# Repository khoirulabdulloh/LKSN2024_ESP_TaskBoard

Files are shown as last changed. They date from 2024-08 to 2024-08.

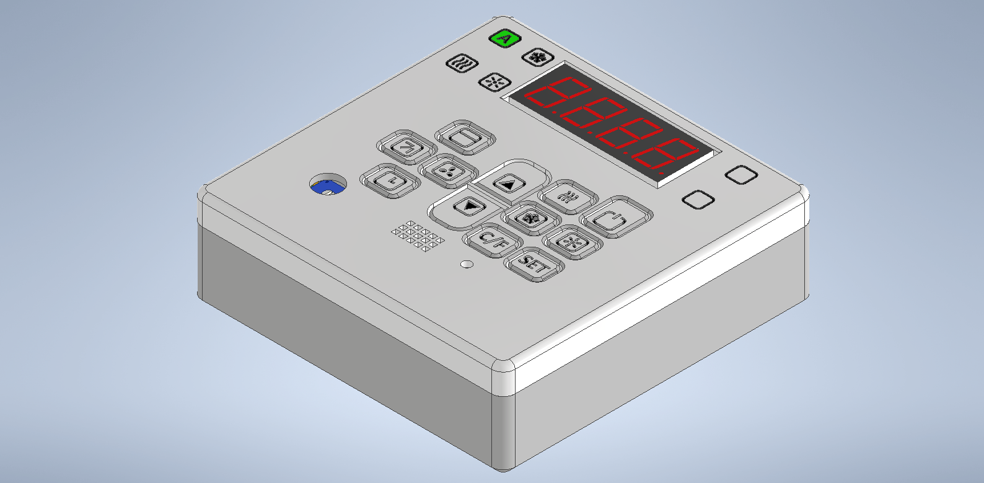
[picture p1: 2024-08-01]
Assembly_LKS2024_ESP_ACController_2.png

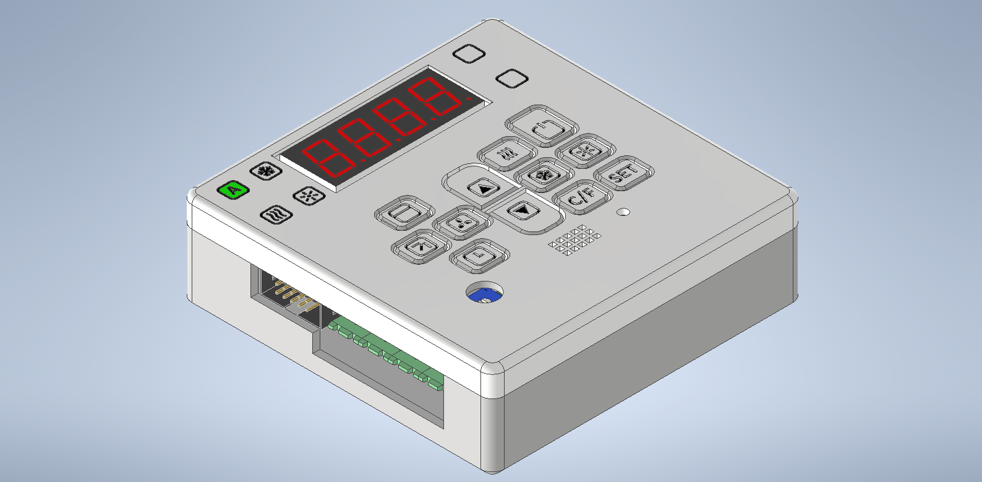
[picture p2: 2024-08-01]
Assembly_LKS2024_ESP_ACController_3.png

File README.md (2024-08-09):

# LKSN2024_ESP_TaskBoard
Embedded System Programming Task Board for Lomba Kompetensi Siswa Nasional Tahun 2024

 -Template_Program berisi template untuk pemrogramaan saat lomba, template akan terus update hingga H-3 perlombaan
 
 -file *.sch* merupakan schematic file EAGLE atau Fusion360

 -file *.brd* merupakan layout file EAGLE atau Fusion360

 -Schematic .pdf merupakan schematic file yang sudah di export dalam PDF

 -file .png merupakan foto dari TaskProject

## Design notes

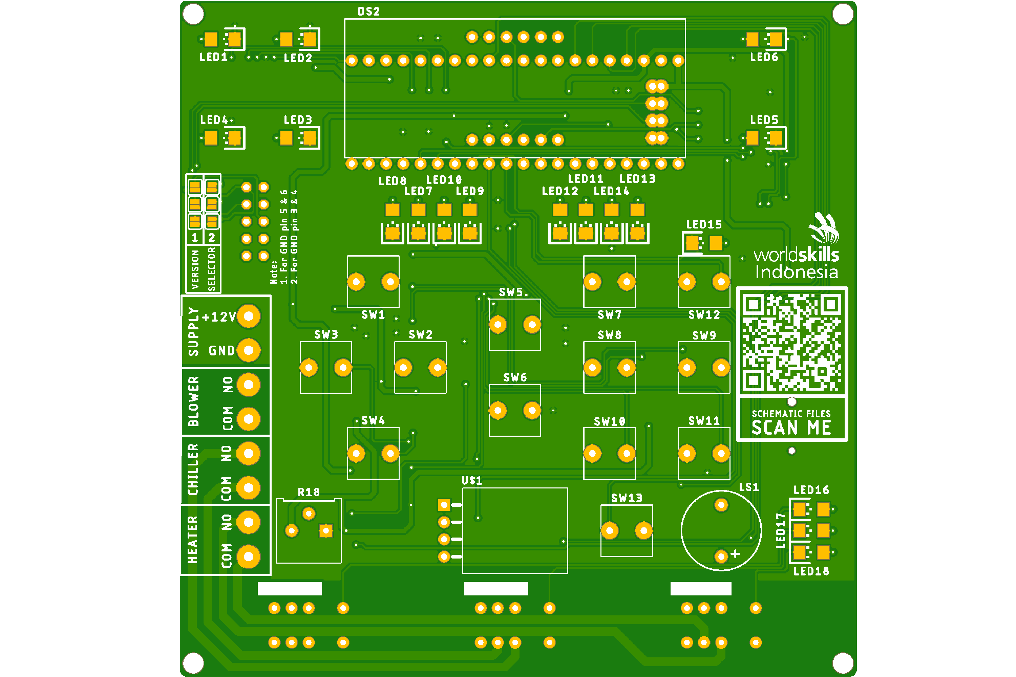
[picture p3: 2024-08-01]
TopSide_LKS2024_ESP_ACController.png

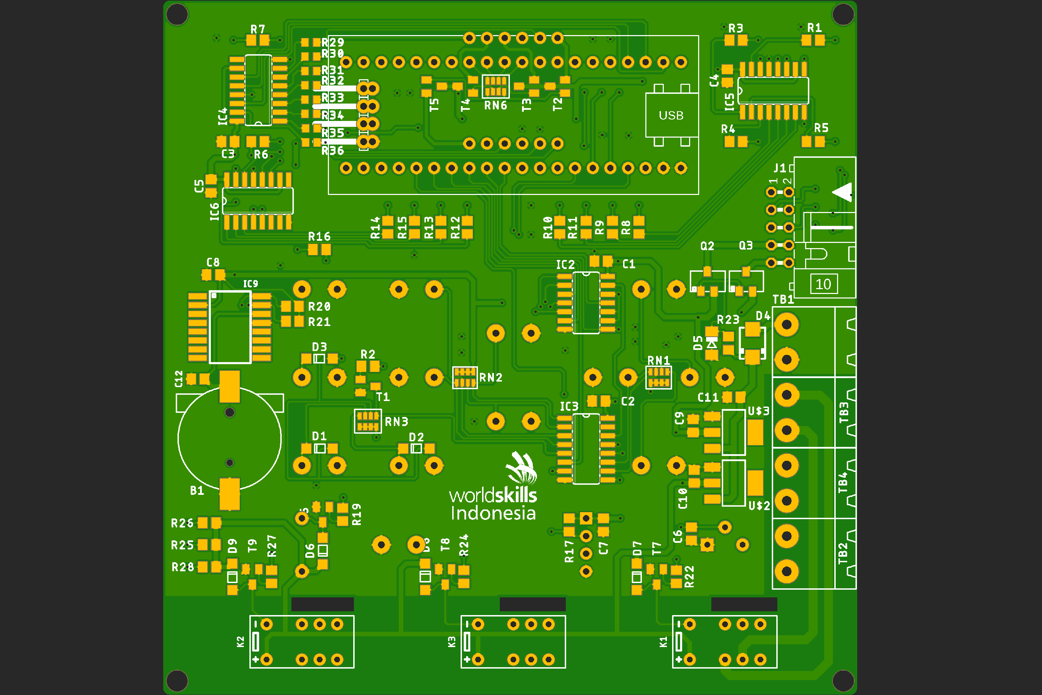
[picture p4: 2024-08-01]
BottomSide_LKS2024_ESP_ACController.png

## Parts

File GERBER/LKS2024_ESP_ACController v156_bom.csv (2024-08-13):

Comment | Designator | Footprint | LCSC Part #
 | J1 | ML10L
1N4148T4 | D1 D2 D3 D6 D7 D8 D9 | SOD123
1k | RN6 | 0603-ARC
1k | R2 R16 R19 R22 R24 R27 | R0805
1k5 | R1 R3 R4 R5 R6 R7 R8 R9 R10 R11 R12 R13 R14 R15 | R0805
3V3 | U$3 | SOT223
4k7 | R20 R21 | R0805
5V | U$2 | SOT223
5V1 | D5 | SOD80C
5k | R17 | R0805
7SEG-5463 | DS2 | 5643
10k | RN1 RN2 RN3 | 0603-ARC
10k | R18 | TRIM_3386P-1-101T
74HCT595D | IC4 IC5 IC6 | SO16
74LS08D | IC2 | SO14
74LS148D | IC3 | SO16
75 | R29 R30 R31 R32 R33 R34 R35 R36 | R0603
100k | R23 | R0805
100n | C1 C2 C3 C4 C5 C6 C7 C8 C9 C10 C11 C12 | C0805
330 | R25 R26 R28 | R0805
AO3404 | Q2 Q3 | SOT23
BLOWER | TB3 | MSTBA2
BLUE | LED2 LED8 LED12 | CHIPLED_1206
BUZZER-PTH_KIT | LS1 | BUZZER-12MM-KIT
C/F | SW10 | PUSH_BUTTON_2P
CHILLER | TB4 | MSTBA2
CR1220 | B1 | CR1220
DHT11 | U$1 | DHT11
DS3231" | IC9 | SO16W
EC2 | K1 K2 K3 | EC2
F_COOL | SW8 | PUSH_BUTTON_2P
F_HEAT | SW9 | PUSH_BUTTON_2P
GREEN | LED1 LED7 LED9 LED10 LED11 LED13 LED14 LED15 LED16 LED17 LED18 | CHIPLED_1206
HEATER | TB2 | MSTBA2
HEATING | SW7 | PUSH_BUTTON_2P
JUMPER-SMT_2_NC_PASTE_SILK | JP3 JP4 JP5 JP8 JP9 JP10 | SMT-JUMPER_2_NC_PASTE_SILK
MMBT3904 | T1 T2 T3 T4 T5 T6 T7 T8 T9 | SOT23-BEC
MODE | SW1 | PUSH_BUTTON_2P
ON/OFF | SW12 | PUSH_BUTTON_2P
RED | LED3 | CHIPLED_1206
RST | SW13 | PUSH_BUTTON_2P
SET | SW11 | PUSH_BUTTON_2P
SPEED | SW2 | PUSH_BUTTON_2P
SS34 | D4 | SMA
STM32F103C8T6-MODULE-SYS | IC1 | STM32F103C8T6-MODULE-SYS
SUPPLY | TB1 | MSTBA2
SWEEP | SW3 | PUSH_BUTTON_2P
TEMP_DOWN | SW6 | PUSH_BUTTON_2P
TEMP_UP | SW5 | PUSH_BUTTON_2P
TIMER | SW4 | PUSH_BUTTON_2P
WHITE | LED4 LED5 LED6 | CHIPLED_1206

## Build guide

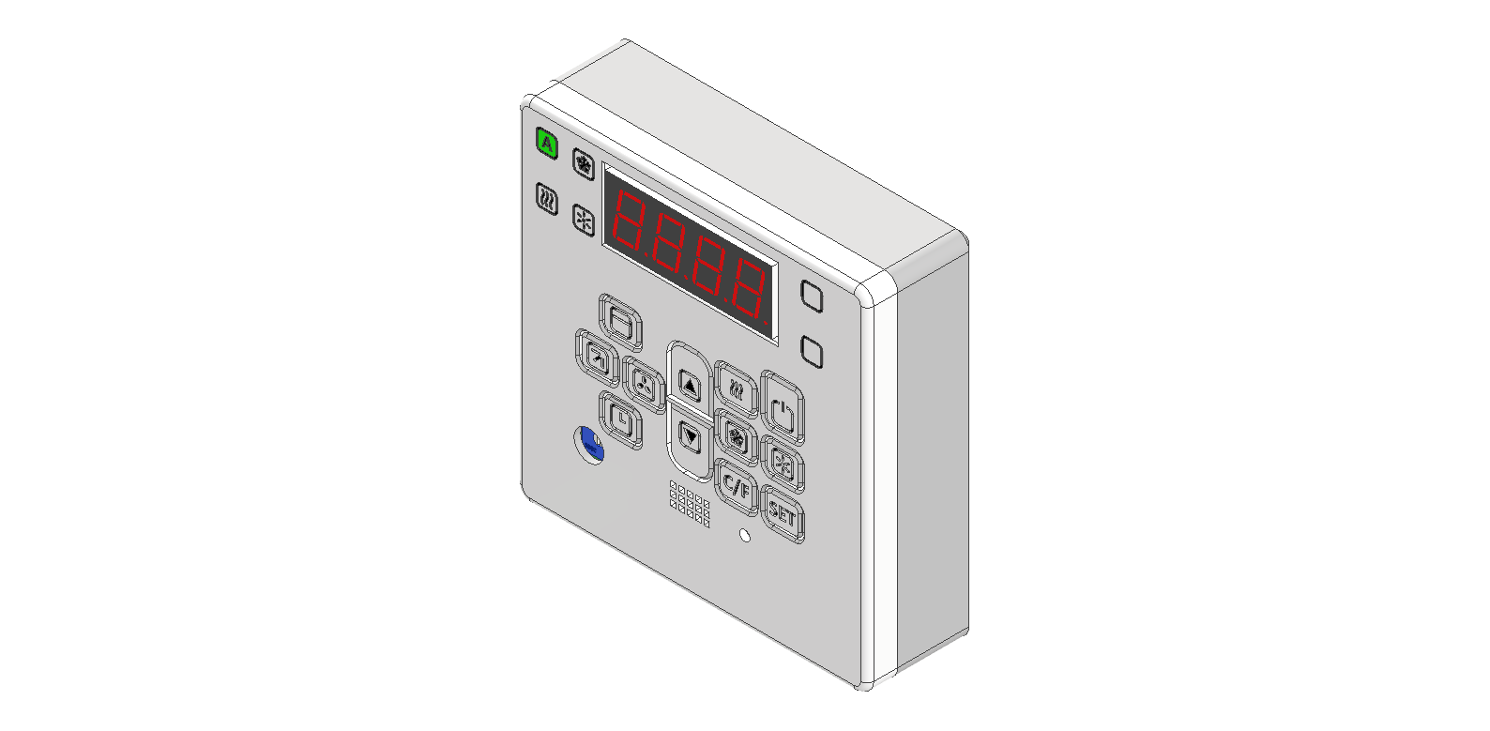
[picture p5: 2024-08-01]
Assembly_LKS2024_ESP_ACController_1.png

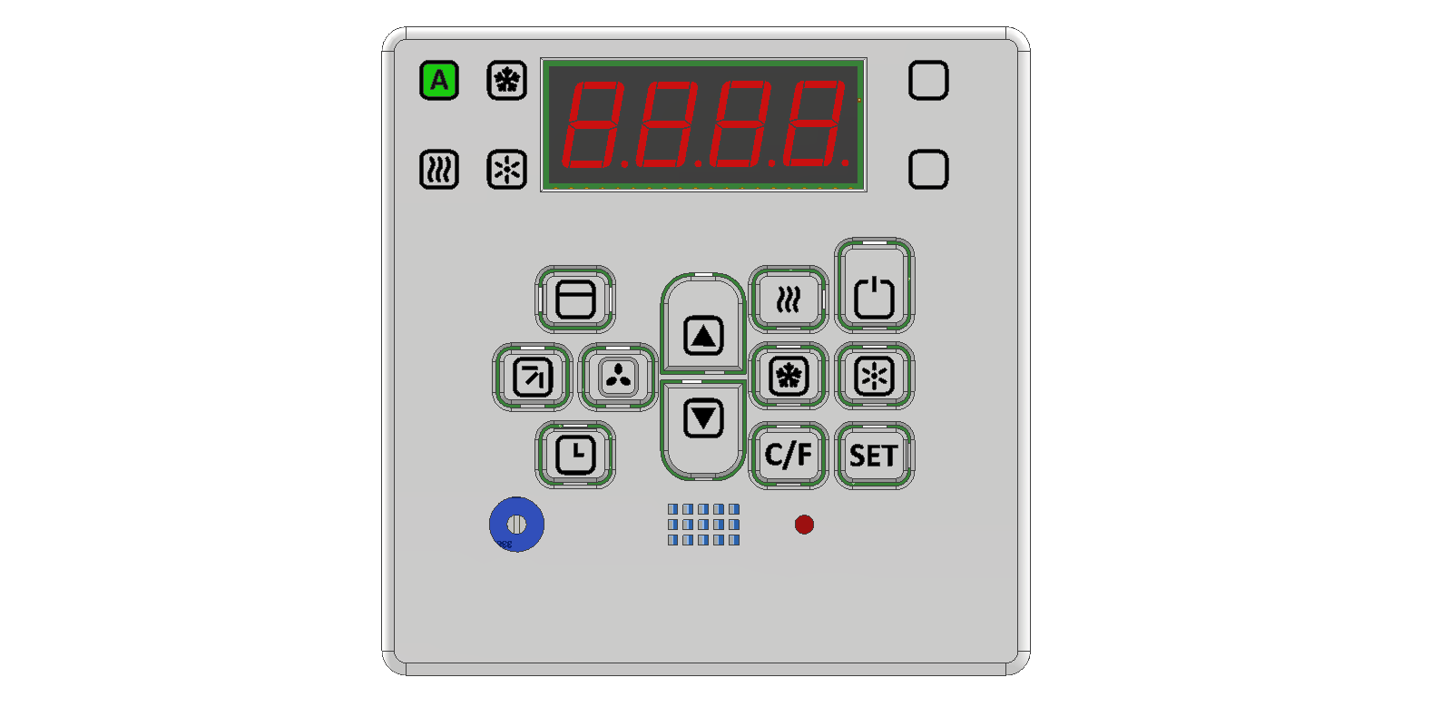
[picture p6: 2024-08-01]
Assembly_LKS2024_ESP_ACController v13.png

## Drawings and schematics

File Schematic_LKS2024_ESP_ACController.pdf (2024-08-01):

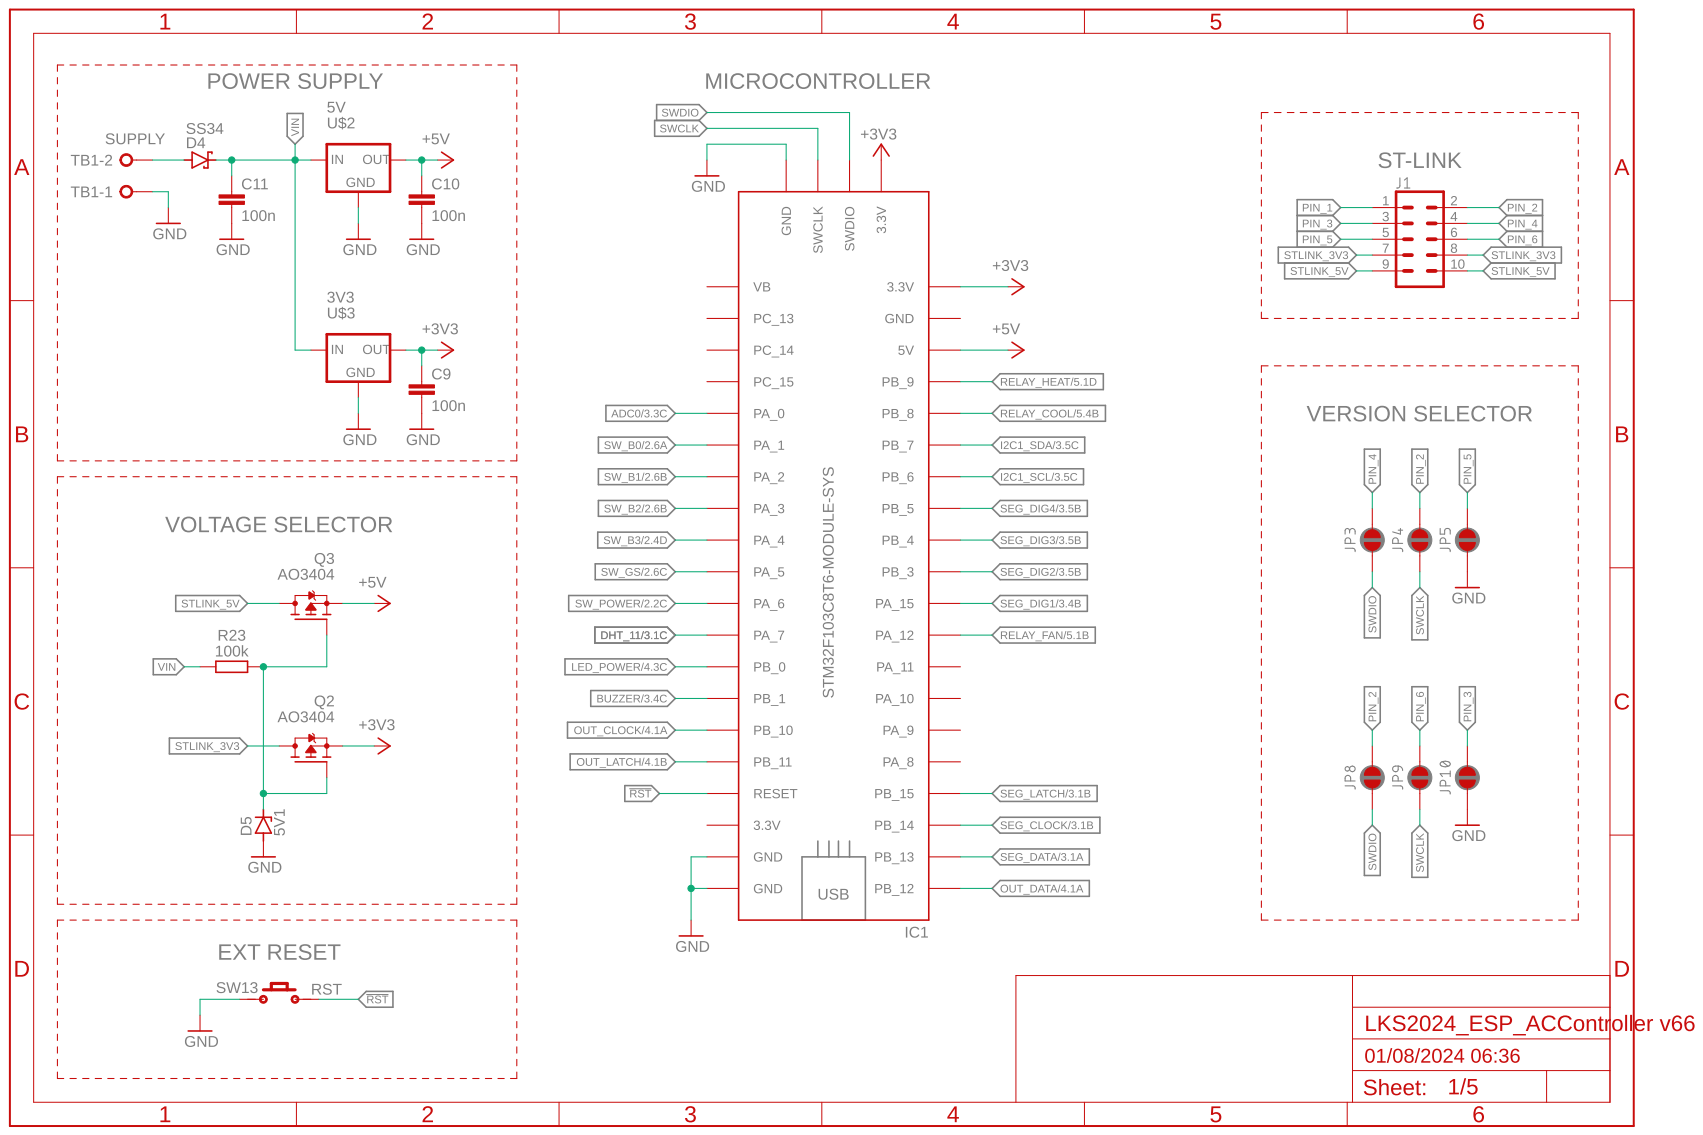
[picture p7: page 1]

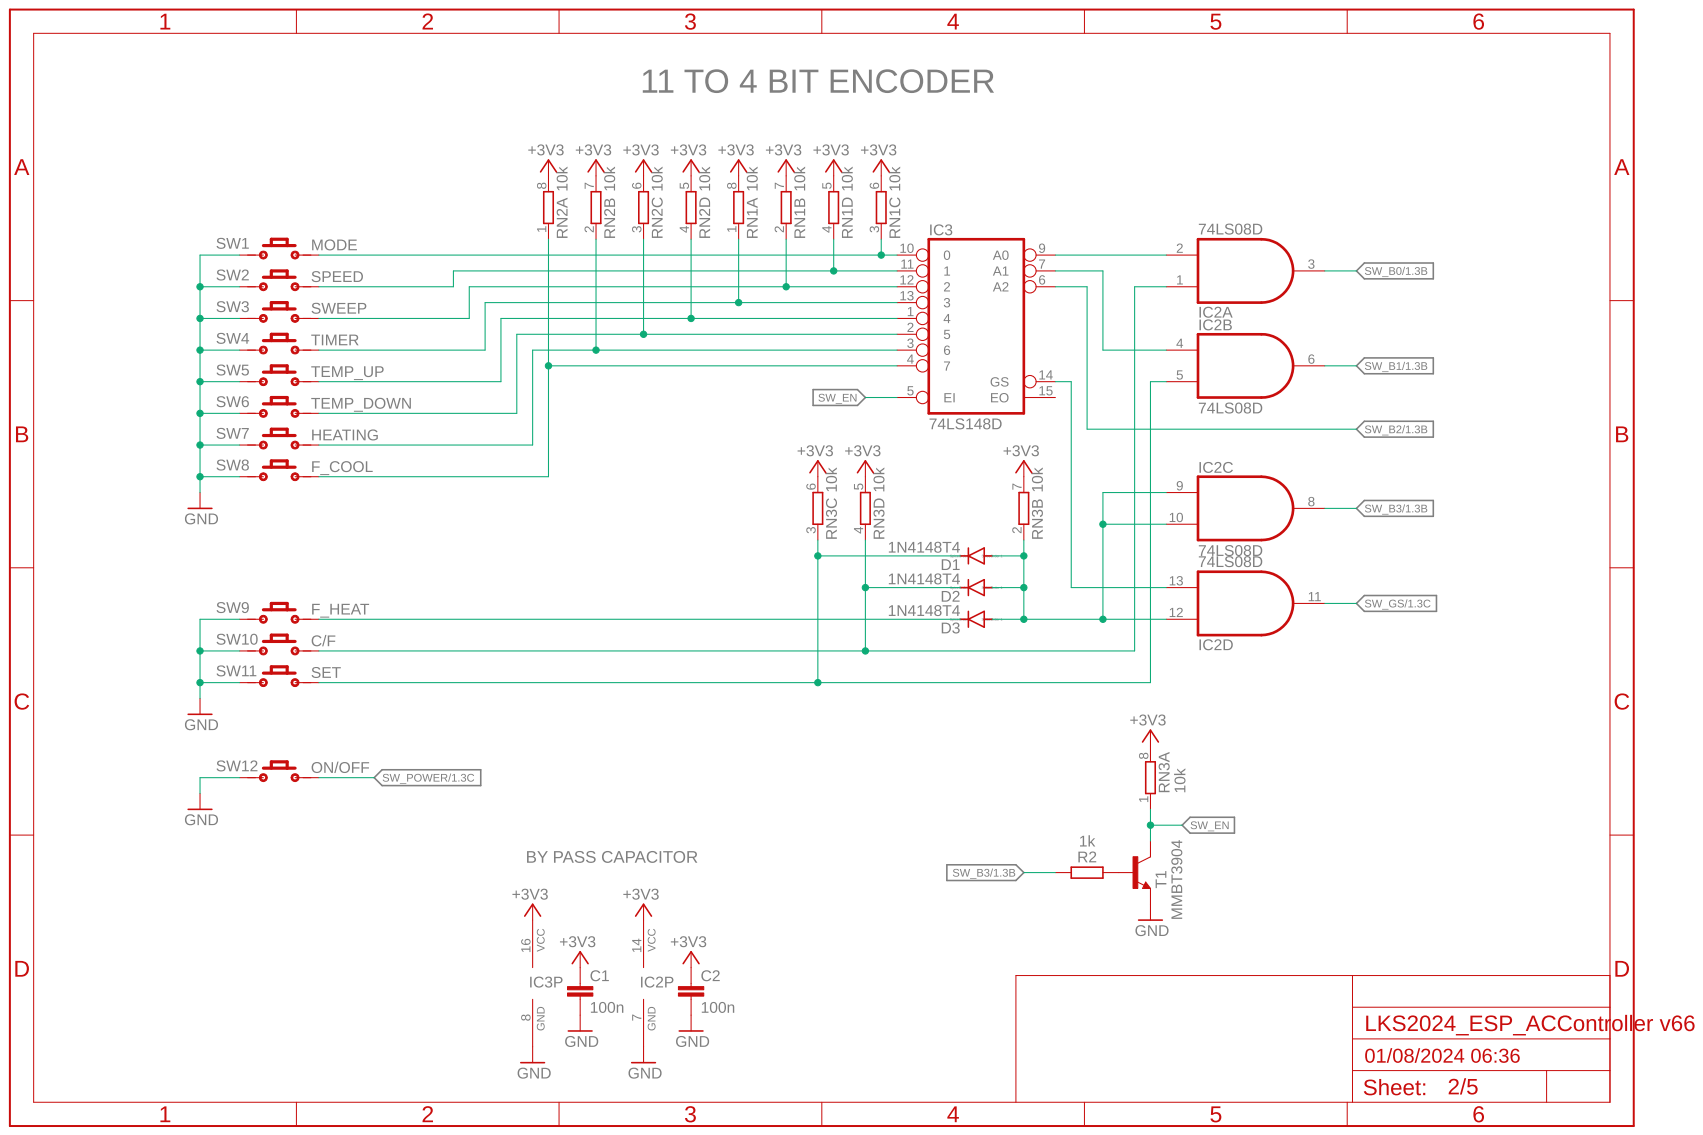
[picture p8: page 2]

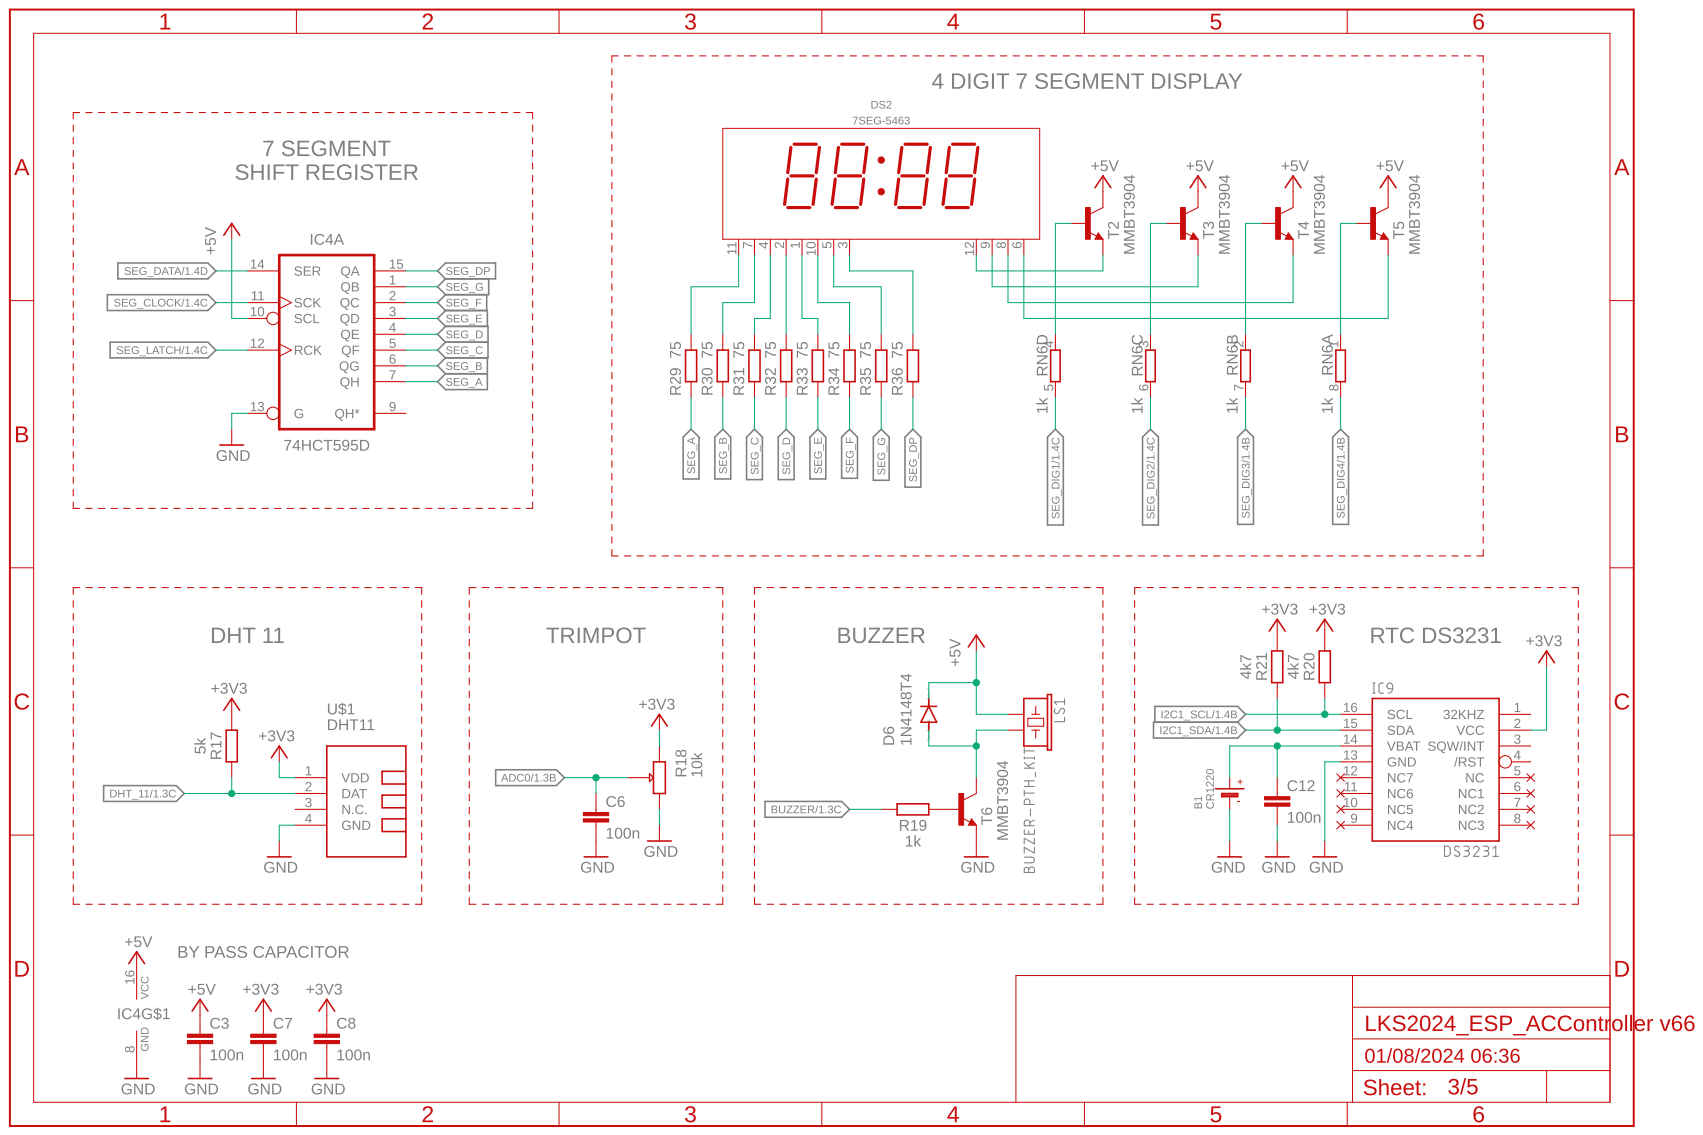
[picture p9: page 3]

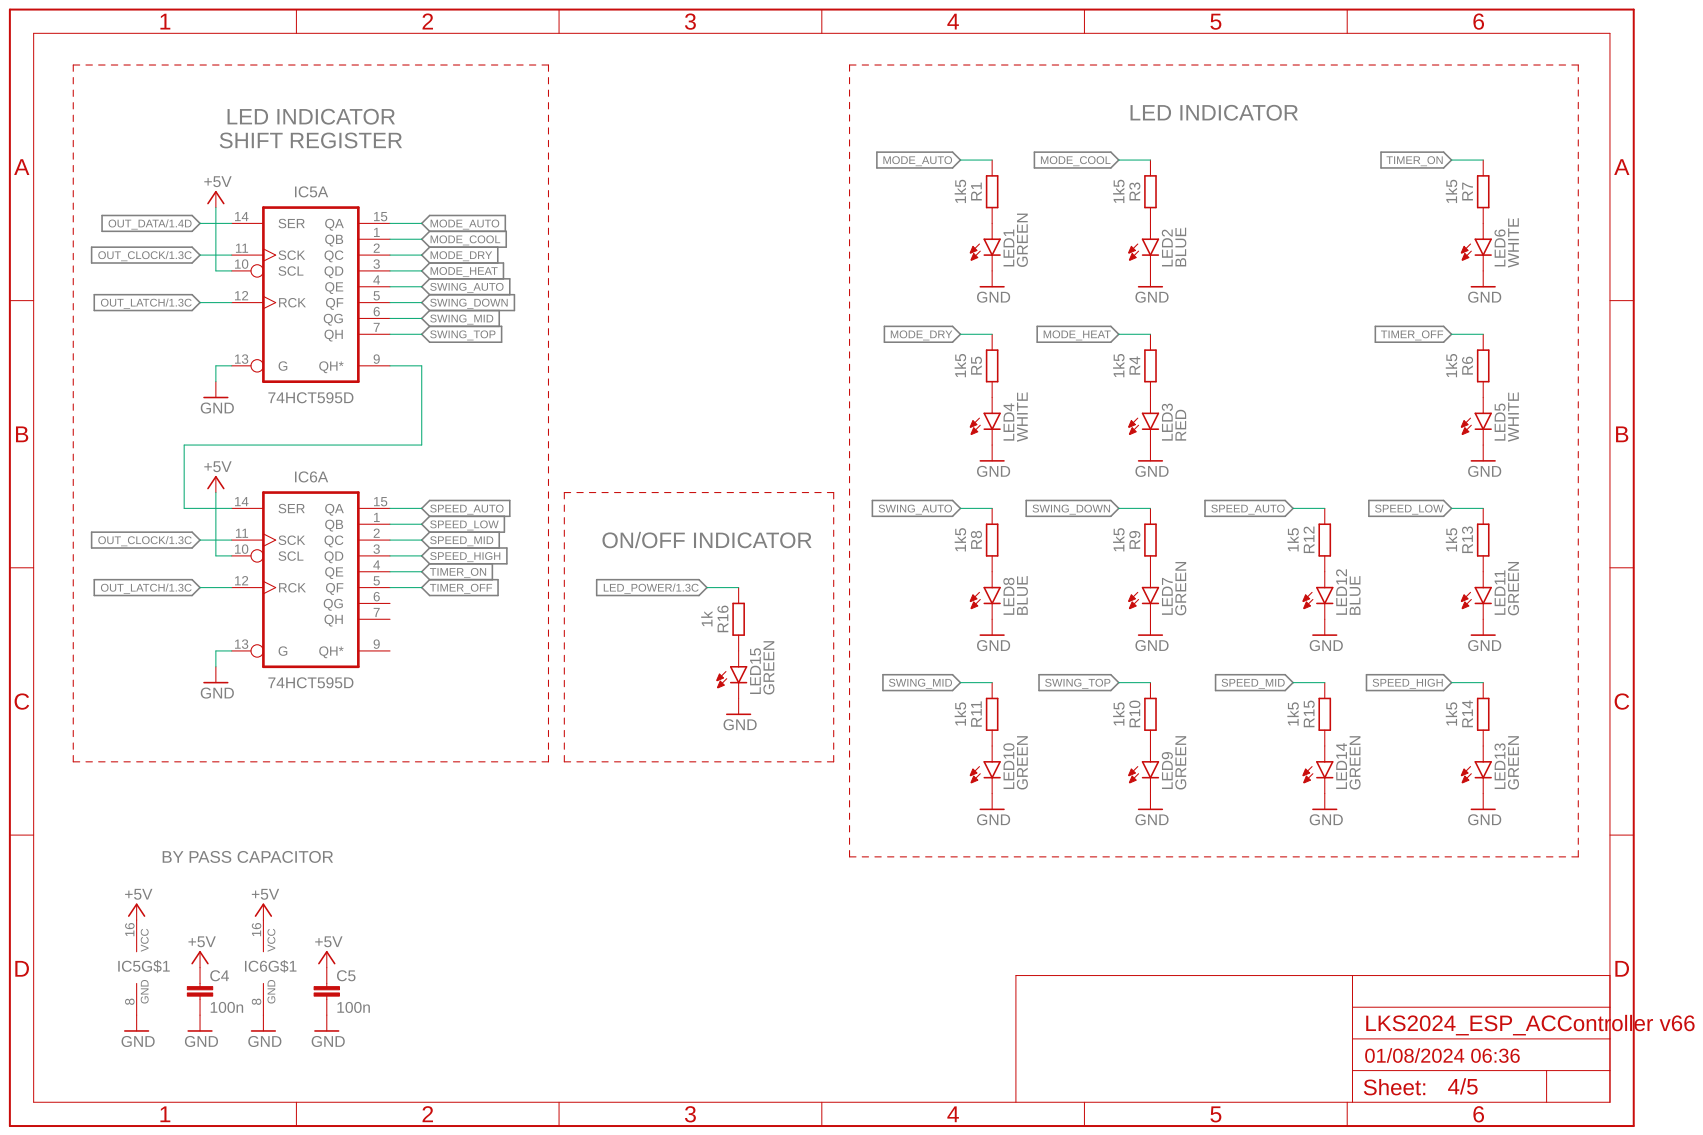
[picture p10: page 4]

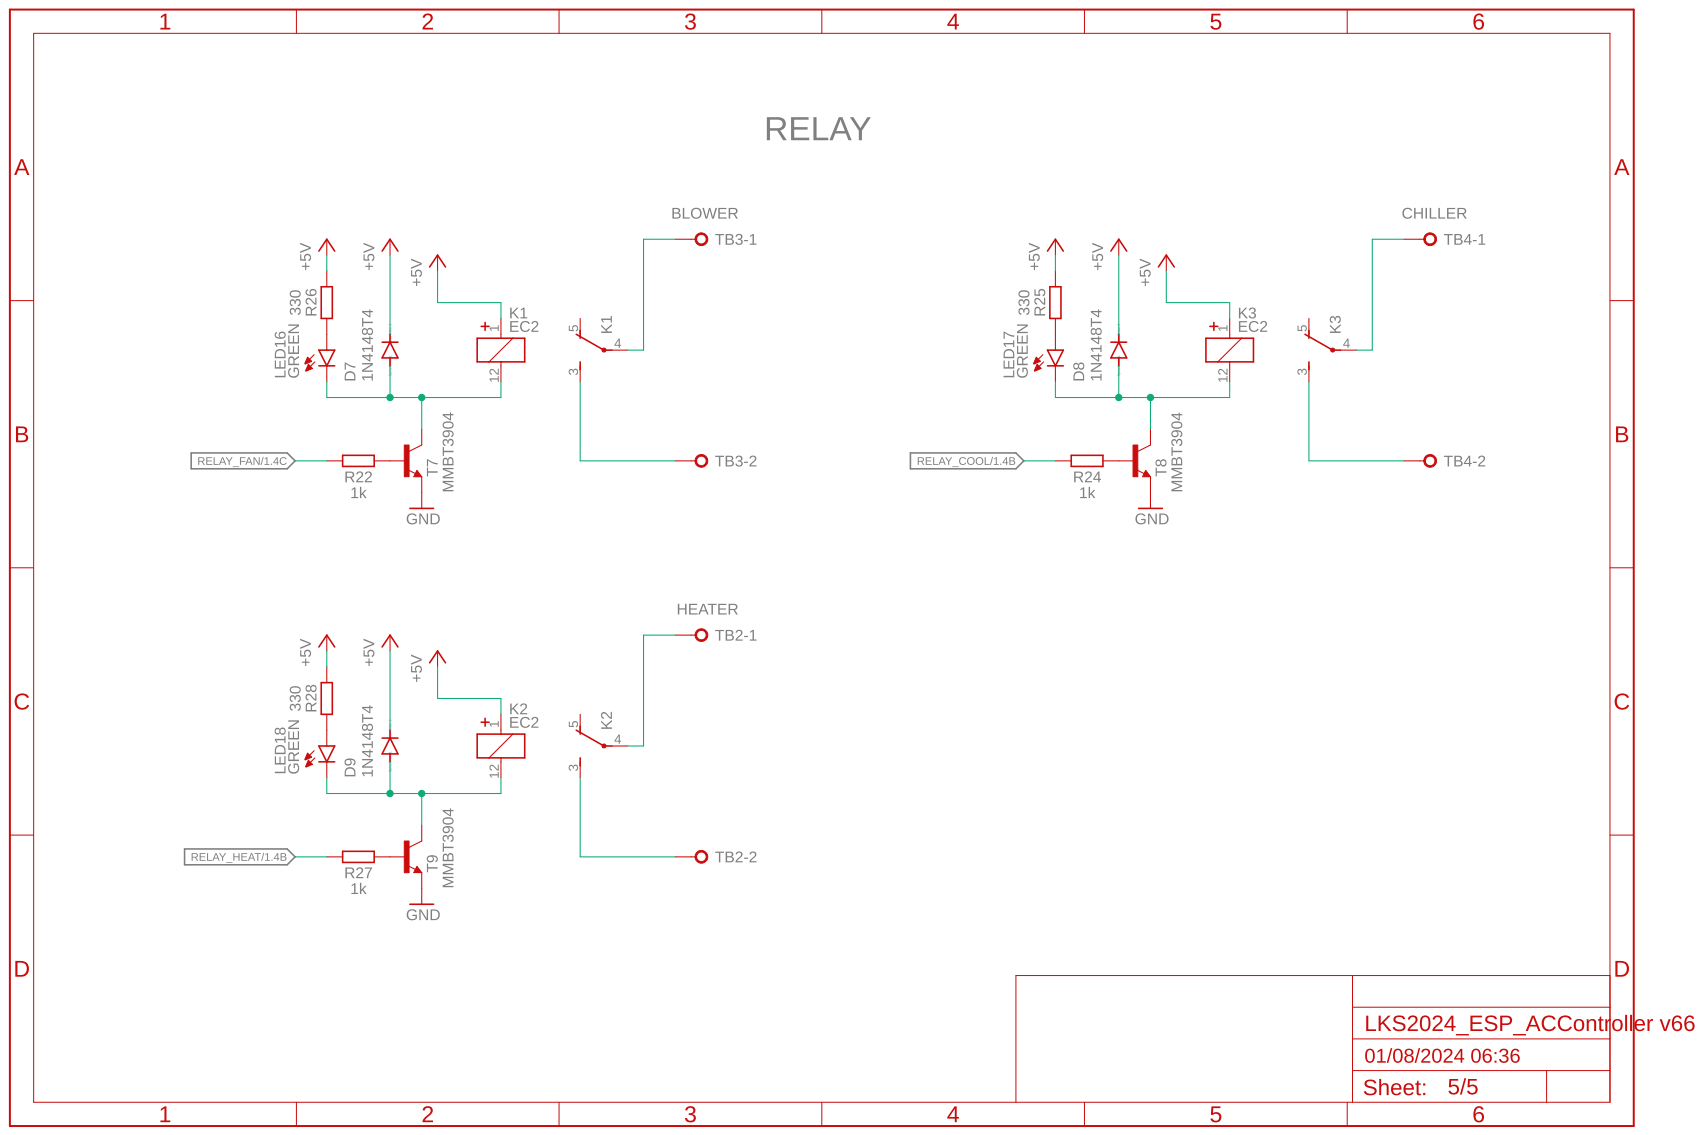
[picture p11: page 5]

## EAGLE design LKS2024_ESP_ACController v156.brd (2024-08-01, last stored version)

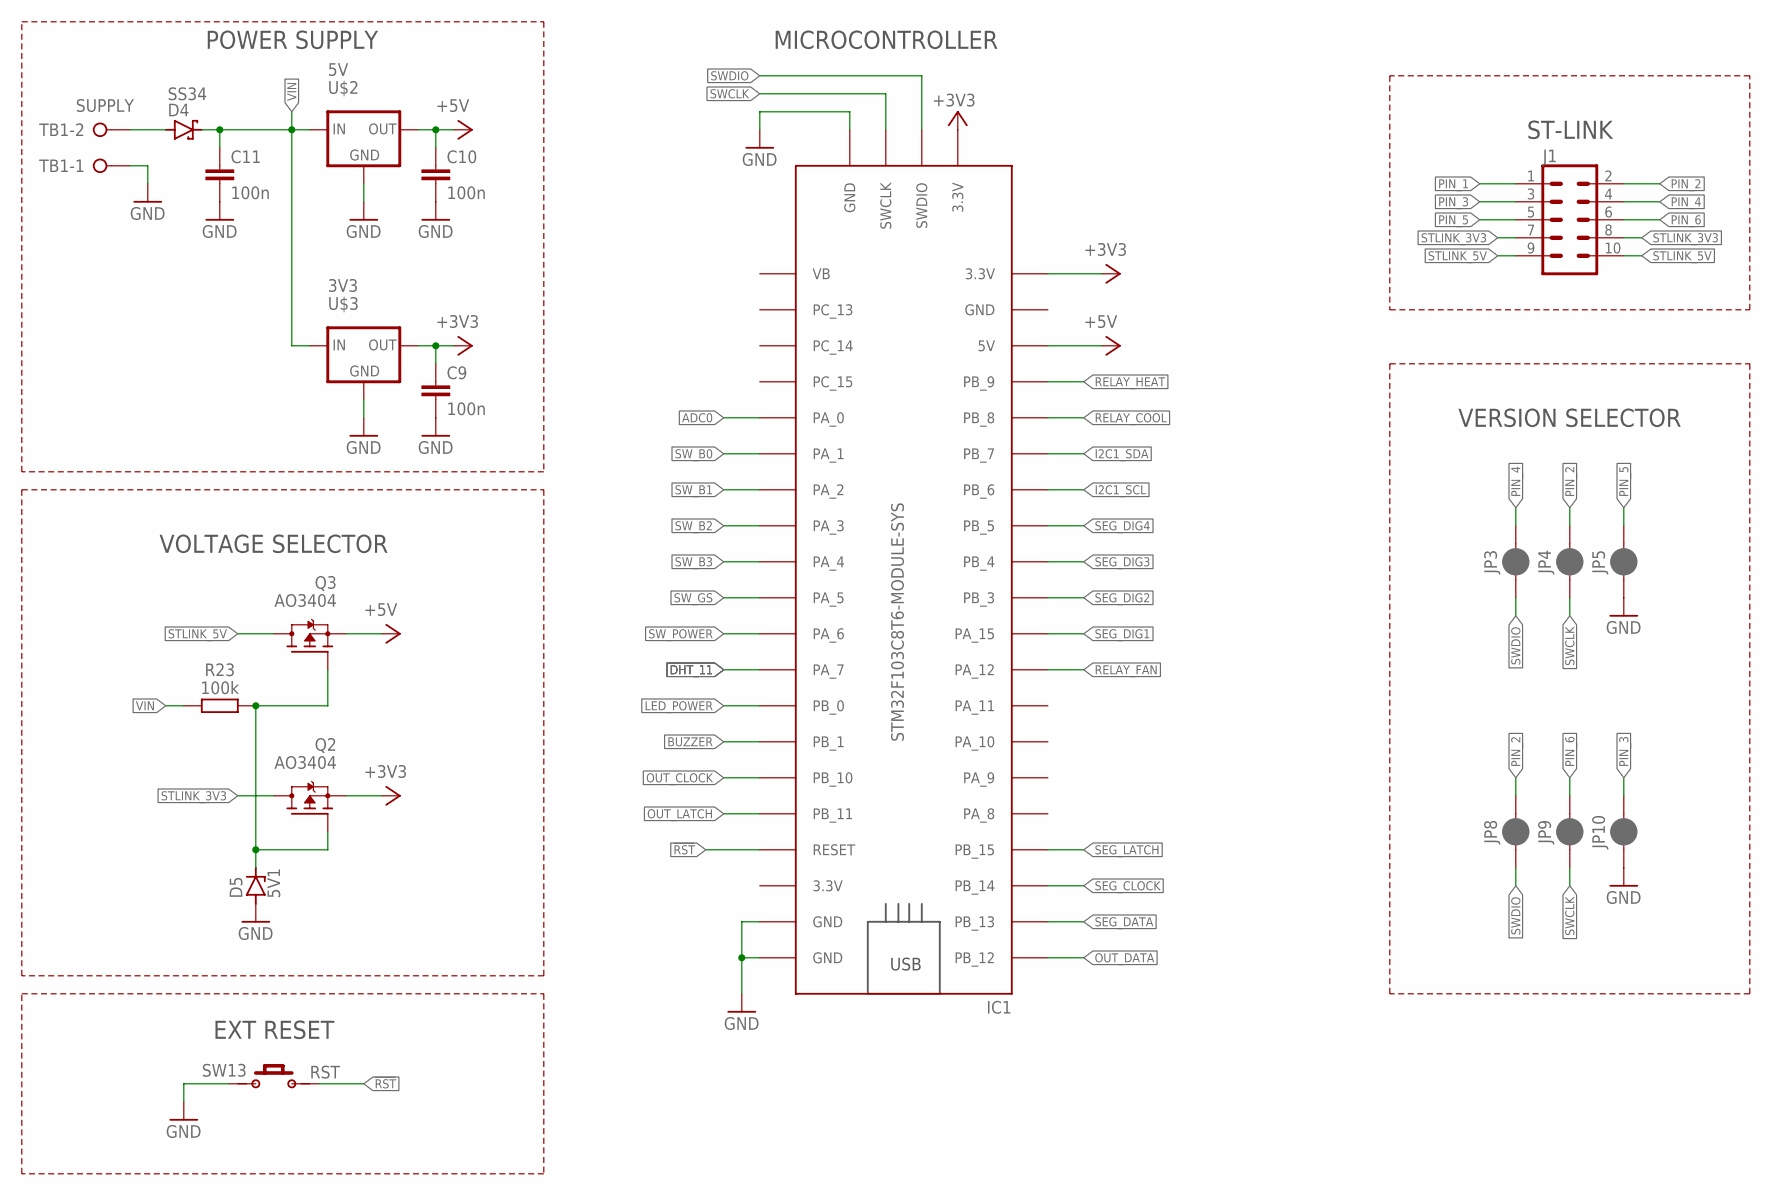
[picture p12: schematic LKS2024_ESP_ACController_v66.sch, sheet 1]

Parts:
C9, C10, C11: 100n; C0805
D4: SS34; SMA
D5: 5V1; SOD80C
IC1: STM32F103C8T6-MODULE-SYS
J1: CONN_05X2ML10L; ML10L
JP3, JP4, JP5, JP8, JP9, JP10: JUMPER-SMT_2_NC_PASTE_SILK; SMT-JUMPER_2_NC_PASTE_SILK
Q2, Q3: AO3404; SOT23
R23: 100k; R0805
SW13: RST; PUSH_BUTTON_2P
TB1: SUPPLY; MSTBA2
U$2: 5V; SOT223
U$3: 3V3; SOT223

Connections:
!RST: IC1.RESET, SW13.2
+3V3: C9.1, IC1.3.3V_1 (3.3V), IC1.3V3_1 (3.3V), IC1.3V3_3 (3.3V), Q2.2 (S), U$3.2 (OUT); also elsewhere on the board
+5V: C10.1, IC1.5V, Q3.2 (S), U$2.2 (OUT); also elsewhere on the board
ADC0: IC1.PA_0; also elsewhere on the board
BUZZER: IC1.PB_1; also elsewhere on the board
DHT_11: IC1.PA_7; also elsewhere on the board
GND: C9.2, C10.2, C11.2, D5.A, IC1.GND_2 (GND), IC1.GND_3 (GND), IC1.GND_4 (GND), IC1.GND_5 (GND), JP5.1, JP10.1, SW13.1, TB1.1, U$2.1 (GND), U$3.1 (GND); also elsewhere on the board
I2C1_SCL: IC1.PB_6; also elsewhere on the board
I2C1_SDA: IC1.PB_7; also elsewhere on the board
LED_POWER: IC1.PB_0; also elsewhere on the board
unnamed: D4.A, TB1.2
unnamed: D5.C, Q2.1 (G), Q3.1 (G), R23.2
OUT_CLOCK: IC1.PB_10; also elsewhere on the board
OUT_DATA: IC1.PB_12; also elsewhere on the board
OUT_LATCH: IC1.PB_11; also elsewhere on the board
PIN_1: J1.1
PIN_2: J1.2, JP4.2, JP8.2
PIN_3: J1.3, JP10.2
PIN_4: J1.4, JP3.2
PIN_5: J1.5, JP5.2
PIN_6: J1.6, JP9.2
RELAY_COOL: IC1.PB_8; also elsewhere on the board
RELAY_FAN: IC1.PA_12; also elsewhere on the board
RELAY_HEAT: IC1.PB_9; also elsewhere on the board
SEG_CLOCK: IC1.PB_14; also elsewhere on the board
SEG_DATA: IC1.PB_13; also elsewhere on the board
SEG_DIG1: IC1.PA_15; also elsewhere on the board
SEG_DIG2: IC1.PB_3; also elsewhere on the board
SEG_DIG3: IC1.PB_4; also elsewhere on the board
SEG_DIG4: IC1.PB_5; also elsewhere on the board
SEG_LATCH: IC1.PB_15; also elsewhere on the board
STLINK_3V3: J1.7, J1.8, Q2.3 (D)
STLINK_5V: J1.9, J1.10, Q3.3 (D)
SWCLK: IC1.SWCLK, IC1.SWCLK1 (SWCLK), JP4.1, JP9.1
SWDIO: IC1.SWDIO, IC1.SWDIO1 (SWDIO), JP3.1, JP8.1
SW_B0: IC1.PA_1; also elsewhere on the board
SW_B1: IC1.PA_2; also elsewhere on the board
SW_B2: IC1.PA_3; also elsewhere on the board
SW_B3: IC1.PA_4; also elsewhere on the board
SW_GS: IC1.PA_5; also elsewhere on the board
SW_POWER: IC1.PA_6; also elsewhere on the board
VIN: C11.1, D4.C, R23.1, U$2.3 (IN), U$3.3 (IN)

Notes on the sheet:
POWER SUPPLY
VOLTAGE SELECTOR
EXT RESET
ST-LINK
VERSION SELECTOR
MICROCONTROLLER

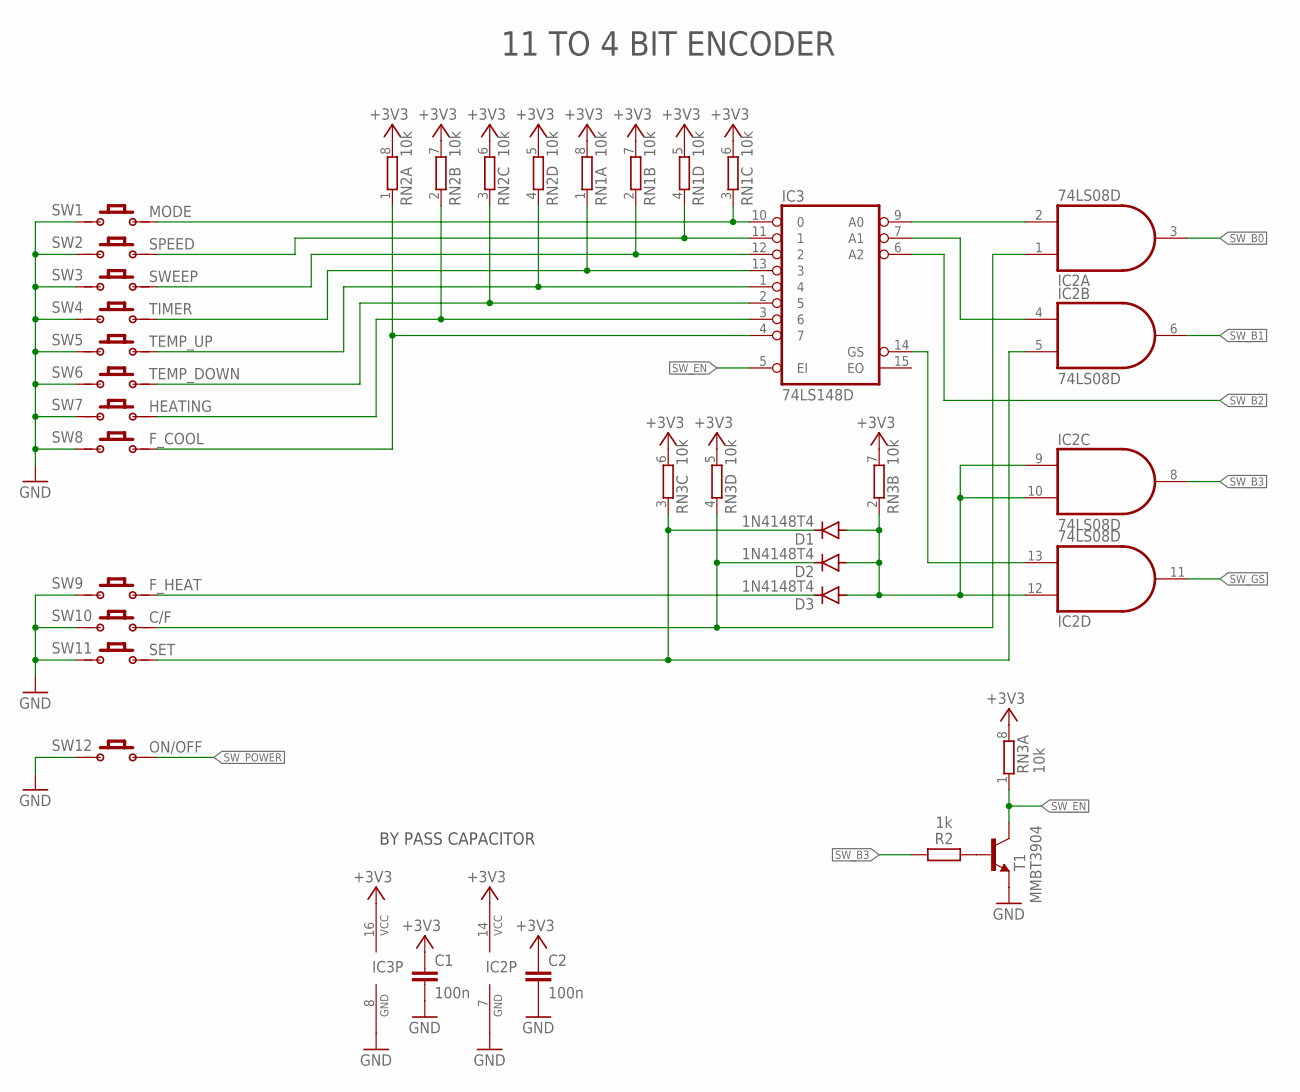
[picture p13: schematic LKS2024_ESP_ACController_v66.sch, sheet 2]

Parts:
C1, C2: 100n; C0805
D1, D2, D3: 1N4148T4; SOD123
IC2: 74LS08D; SO14
IC3: 74LS148D; SO16
R2: 1k; R0805
RN1, RN2, RN3: 10k; 0603-ARC
SW1: MODE; PUSH_BUTTON_2P
SW2: SPEED; PUSH_BUTTON_2P
SW3: SWEEP; PUSH_BUTTON_2P
SW4: TIMER; PUSH_BUTTON_2P
SW5: TEMP_UP; PUSH_BUTTON_2P
SW6: TEMP_DOWN; PUSH_BUTTON_2P
SW7: HEATING; PUSH_BUTTON_2P
SW8: F_COOL; PUSH_BUTTON_2P
SW9: F_HEAT; PUSH_BUTTON_2P
SW10: C/F; PUSH_BUTTON_2P
SW11: SET; PUSH_BUTTON_2P
SW12: ON/OFF; PUSH_BUTTON_2P
T1: MMBT3904; SOT23-BEC

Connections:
+3V3: C1.1, C2.1, IC2.14 (VCC), IC3.16 (VCC), RN1.5 (2), RN1.6 (2), RN1.7 (2), RN1.8 (2), RN2.5 (2), RN2.6 (2), RN2.7 (2), RN2.8 (2), RN3.5 (2), RN3.6 (2), RN3.7 (2), RN3.8 (2); also elsewhere on the board
GND: C1.2, C2.2, IC2.7 (GND), IC3.8 (GND), SW1.1, SW2.1, SW3.1, SW4.1, SW5.1, SW6.1, SW7.1, SW8.1, SW9.1, SW10.1, SW11.1, SW12.1, T1.E; also elsewhere on the board
unnamed: IC2.2 (I1), IC3.9 (A0)
unnamed: IC2.4 (I0), IC3.7 (A1)
unnamed: IC2.13 (I1), IC3.14 (GS)
unnamed: D1.A, D2.A, D3.A, IC2.9 (I0), IC2.10 (I1), IC2.12 (I0), RN3.2 (1)
unnamed: IC3.10 (0), RN1.3 (1), SW1.2
unnamed: IC3.11 (1), RN1.4 (1), SW2.2
unnamed: IC3.12 (2), RN1.2 (1), SW3.2
unnamed: IC3.13 (3), RN1.1, SW4.2
unnamed: IC3.1 (4), RN2.4 (1), SW5.2
unnamed: IC3.2 (5), RN2.3 (1), SW6.2
unnamed: IC3.3 (6), RN2.2 (1), SW7.2
unnamed: IC3.4 (7), RN2.1, SW8.2
unnamed: D3.C, SW9.2
unnamed: D2.C, IC2.1 (I0), RN3.4 (1), SW10.2
unnamed: D1.C, IC2.5 (I1), RN3.3 (1), SW11.2
unnamed: R2.1, T1.B
SW_B0: IC2.3 (O); also elsewhere on the board
SW_B1: IC2.6 (O); also elsewhere on the board
SW_B2: IC3.6 (A2); also elsewhere on the board
SW_B3: IC2.8 (O), R2.2; also elsewhere on the board
SW_EN: IC3.5 (EI), RN3.1, T1.C
SW_GS: IC2.11 (O); also elsewhere on the board
SW_POWER: SW12.2; also elsewhere on the board

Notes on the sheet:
11 TO 4 BIT ENCODER
BY PASS CAPACITOR

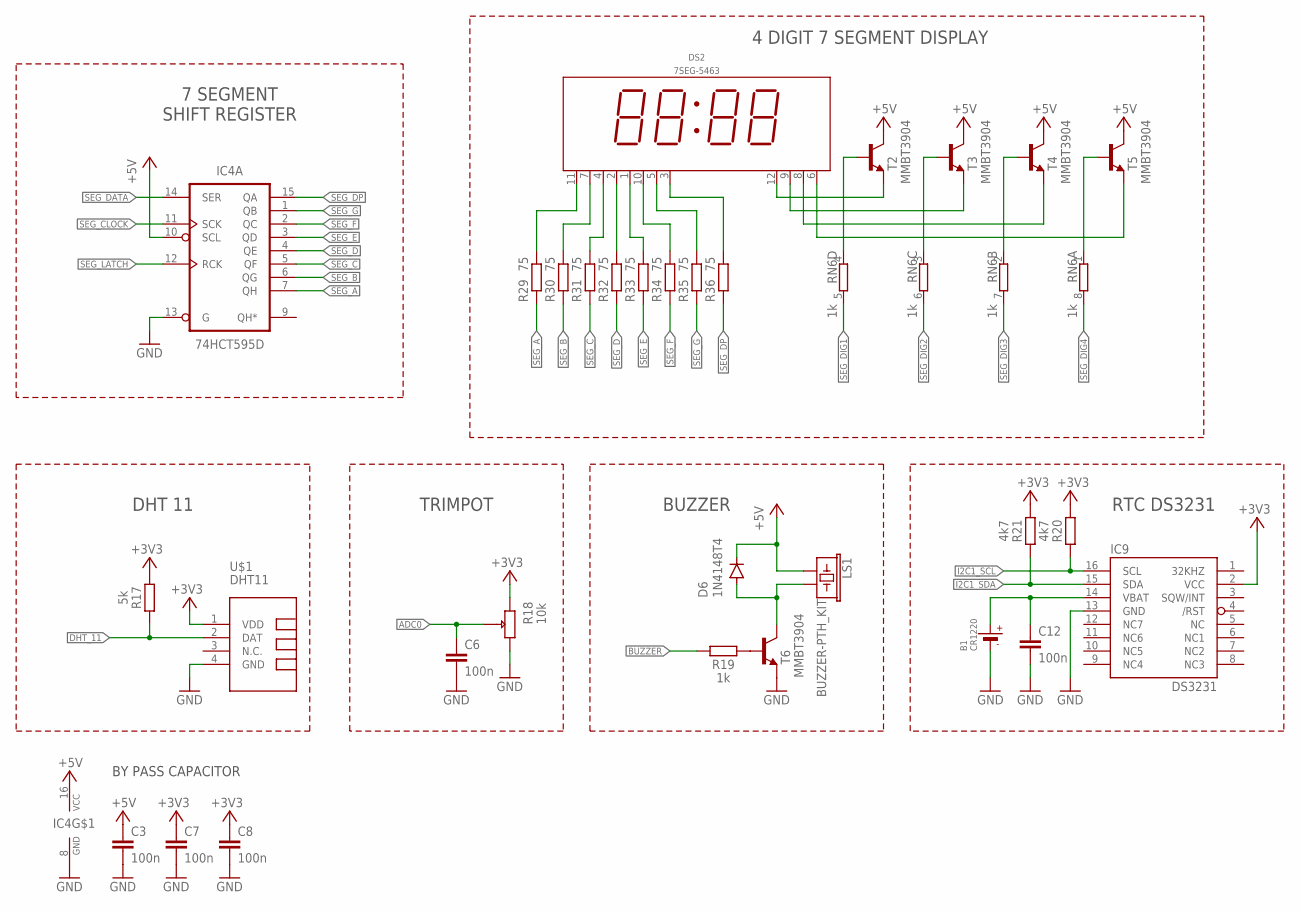
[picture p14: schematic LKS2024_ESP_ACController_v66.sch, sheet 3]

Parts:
B1: CR1220
C3, C6, C7, C8, C12: 100n; C0805
D6: 1N4148T4; SOD123
DS2: 7SEG-5463; 5643
IC4: 74HCT595D; SO16
IC9: DS3231"; SO16W
LS1: BUZZER-PTH_KIT; BUZZER-12MM-KIT
R17: 5k; R0805
R18: 10k; TRIM_3386P-1-101T
R19: 1k; R0805
R20, R21: 4k7; R0805
R29, R30, R31, R32, R33, R34, R35, R36: 75; R0603
RN6: 1k; 0603-ARC
T2, T3, T4, T5, T6: MMBT3904; SOT23-BEC
U$1: DHT11

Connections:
+3V3: C7.1, C8.1, IC9.2 (VCC), R17.1, R18.3 (CW), R20.2, R21.2, U$1.1 (VDD); also elsewhere on the board
+5V: C3.1, D6.C, IC4.10 (SCL), IC4.16 (VCC), LS1.+\ (1), T2.C, T3.C, T4.C, T5.C; also elsewhere on the board
ADC0: C6.1, R18.2 (WIPER); also elsewhere on the board
BUZZER: R19.1; also elsewhere on the board
DHT_11: R17.2, U$1.2 (DAT); also elsewhere on the board
GND: B1.-, C3.2, C6.2, C7.2, C8.2, C12.2, IC4.8 (GND), IC4.13 (G), IC9.13 (GND), R18.1 (CCW), T6.E, U$1.4 (GND); also elsewhere on the board
I2C1_SCL: IC9.16 (SCL), R20.1; also elsewhere on the board
I2C1_SDA: IC9.15 (SDA), R21.1; also elsewhere on the board
unnamed: DS2.12 (DIG1), T2.E
unnamed: DS2.11 (A), R29.2
unnamed: DS2.7 (B), R30.2
unnamed: DS2.4 (C), R31.2
unnamed: DS2.2 (D), R32.2
unnamed: DS2.1 (E), R33.2
unnamed: DS2.10 (F), R34.2
unnamed: DS2.5 (G), R35.2
unnamed: DS2.3 (H), R36.2
unnamed: RN6.4 (1), T2.B
unnamed: DS2.9 (DIG2), T3.E
unnamed: DS2.8 (DIG3), T4.E
unnamed: DS2.6 (DIG4), T5.E
unnamed: RN6.3 (1), T3.B
unnamed: RN6.2 (1), T4.B
unnamed: RN6.1, T5.B
unnamed: D6.A, LS1.- (2), T6.C
unnamed: R19.2, T6.B
unnamed: B1.+, C12.1, IC9.14 (VBAT)
SEG_A: IC4.7 (QH), R29.1
SEG_B: IC4.6 (QG), R30.1
SEG_C: IC4.5 (QF), R31.1
SEG_CLOCK: IC4.11 (SCK); also elsewhere on the board
SEG_D: IC4.4 (QE), R32.1
SEG_DATA: IC4.14 (SER); also elsewhere on the board
SEG_DIG1: RN6.5 (2); also elsewhere on the board
SEG_DIG2: RN6.6 (2); also elsewhere on the board
SEG_DIG3: RN6.7 (2); also elsewhere on the board
SEG_DIG4: RN6.8 (2); also elsewhere on the board
SEG_DP: IC4.15 (QA), R36.1
SEG_E: IC4.3 (QD), R33.1
SEG_F: IC4.2 (QC), R34.1
SEG_G: IC4.1 (QB), R35.1
SEG_LATCH: IC4.12 (RCK); also elsewhere on the board

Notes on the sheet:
4 DIGIT 7 SEGMENT DISPLAY
7 SEGMENT SHIFT REGISTER
RTC DS3231
BUZZER
TRIMPOT
DHT 11
BY PASS CAPACITOR

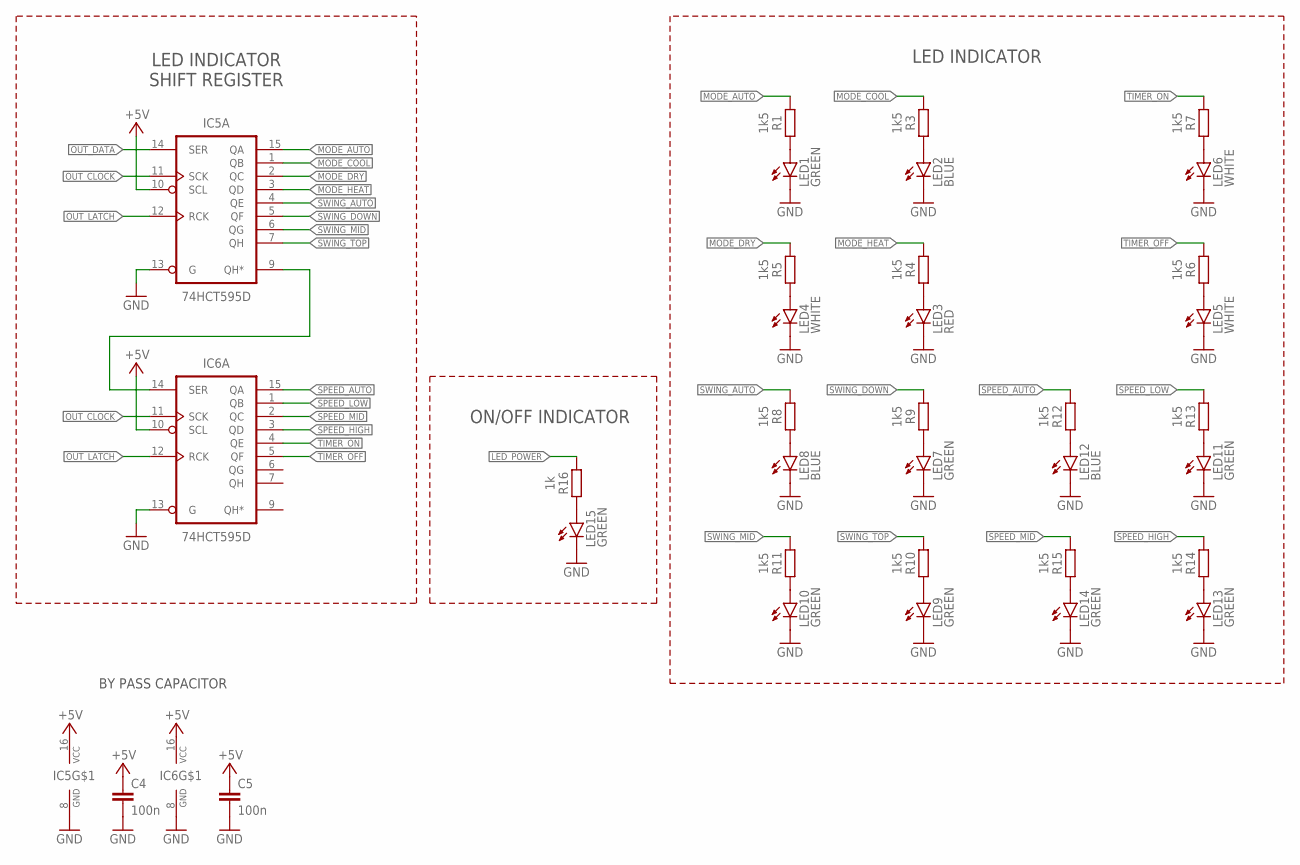
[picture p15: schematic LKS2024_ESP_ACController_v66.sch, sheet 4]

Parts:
C4, C5: 100n; C0805
IC5, IC6: 74HCT595D; SO16
LED1, LED7, LED9, LED10, LED11, LED13, LED14, LED15: GREEN; CHIPLED_1206
LED2, LED8, LED12: BLUE; CHIPLED_1206
LED3: RED; CHIPLED_1206
LED4, LED5, LED6: WHITE; CHIPLED_1206
R1, R3, R4, R5, R6, R7, R8, R9, R10, R11, R12, R13, R14, R15: 1k5; R0805
R16: 1k; R0805

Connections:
+5V: C4.1, C5.1, IC5.10 (SCL), IC5.16 (VCC), IC6.10 (SCL), IC6.16 (VCC); also elsewhere on the board
GND: C4.2, C5.2, IC5.8 (GND), IC5.13 (G), IC6.8 (GND), IC6.13 (G), LED1.C, LED2.C, LED3.C, LED4.C, LED5.C, LED6.C, LED7.C, LED8.C, LED9.C, LED10.C, LED11.C, LED12.C, LED13.C, LED14.C, LED15.C; also elsewhere on the board
LED_POWER: R16.1; also elsewhere on the board
MODE_AUTO: IC5.15 (QA), R1.1
MODE_COOL: IC5.1 (QB), R3.1
MODE_DRY: IC5.2 (QC), R5.1
MODE_HEAT: IC5.3 (QD), R4.1
unnamed: IC5.9 (QH*), IC6.14 (SER)
unnamed: LED1.A, R1.2
unnamed: LED2.A, R3.2
unnamed: LED3.A, R4.2
unnamed: LED4.A, R5.2
unnamed: LED5.A, R6.2
unnamed: LED6.A, R7.2
unnamed: LED8.A, R8.2
unnamed: LED7.A, R9.2
unnamed: LED9.A, R10.2
unnamed: LED10.A, R11.2
unnamed: LED12.A, R12.2
unnamed: LED11.A, R13.2
unnamed: LED13.A, R14.2
unnamed: LED14.A, R15.2
unnamed: LED15.A, R16.2
OUT_CLOCK: IC5.11 (SCK), IC6.11 (SCK); also elsewhere on the board
OUT_DATA: IC5.14 (SER); also elsewhere on the board
OUT_LATCH: IC5.12 (RCK), IC6.12 (RCK); also elsewhere on the board
SPEED_AUTO: IC6.15 (QA), R12.1
SPEED_HIGH: IC6.3 (QD), R14.1
SPEED_LOW: IC6.1 (QB), R13.1
SPEED_MID: IC6.2 (QC), R15.1
SWING_AUTO: IC5.4 (QE), R8.1
SWING_DOWN: IC5.5 (QF), R9.1
SWING_MID: IC5.6 (QG), R11.1
SWING_TOP: IC5.7 (QH), R10.1
TIMER_OFF: IC6.5 (QF), R6.1
TIMER_ON: IC6.4 (QE), R7.1

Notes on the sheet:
LED INDICATOR
ON/OFF INDICATOR
LED INDICATOR SHIFT REGISTER
BY PASS CAPACITOR

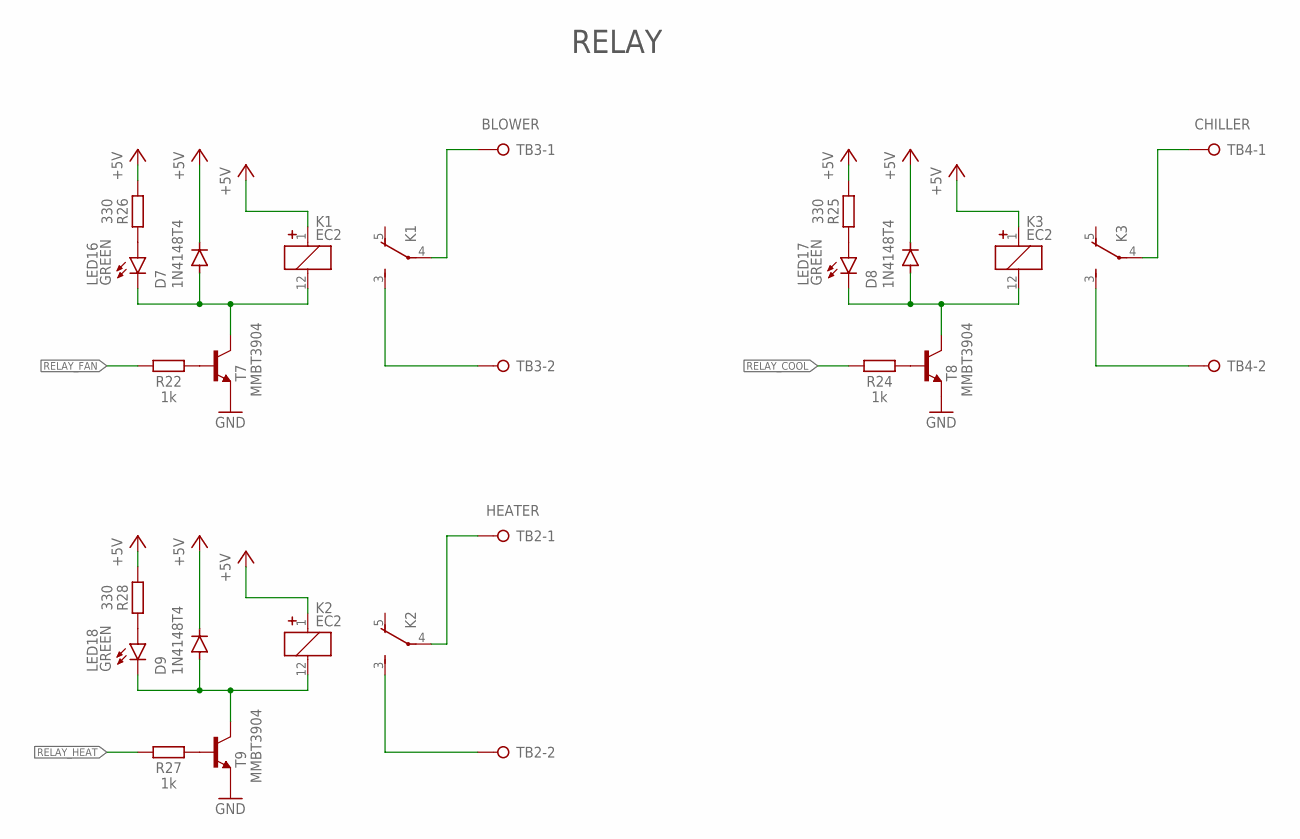
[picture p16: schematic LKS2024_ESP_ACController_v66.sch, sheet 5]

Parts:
D7, D8, D9: 1N4148T4; SOD123
K1, K2, K3: EC2
LED16, LED17, LED18: GREEN; CHIPLED_1206
R22, R24, R27: 1k; R0805
R25, R26, R28: 330; R0805
T7, T8, T9: MMBT3904; SOT23-BEC
TB2: HEATER; MSTBA2
TB3: BLOWER; MSTBA2
TB4: CHILLER; MSTBA2

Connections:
+5V: D7.C, D8.C, D9.C, K1.1 (1+), K2.1 (1+), K3.1 (1+), R25.1, R26.1, R28.1; also elsewhere on the board
GND: T7.E, T8.E, T9.E; also elsewhere on the board
unnamed: D7.A, K1.12 (2-), LED16.C, T7.C
unnamed: R22.2, T7.B
unnamed: D8.A, K3.12 (2-), LED17.C, T8.C
unnamed: R24.2, T8.B
unnamed: LED17.A, R25.2
unnamed: K3.3 (S), TB4.2
unnamed: LED16.A, R26.2
unnamed: K1.3 (S), TB3.2
unnamed: K1.4, TB3.1
unnamed: K3.4, TB4.1
unnamed: D9.A, K2.12 (2-), LED18.C, T9.C
unnamed: R27.2, T9.B
unnamed: LED18.A, R28.2
unnamed: K2.3 (S), TB2.2
unnamed: K2.4, TB2.1
RELAY_COOL: R24.1; also elsewhere on the board
RELAY_FAN: R22.1; also elsewhere on the board
RELAY_HEAT: R27.1; also elsewhere on the board

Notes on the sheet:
RELAY

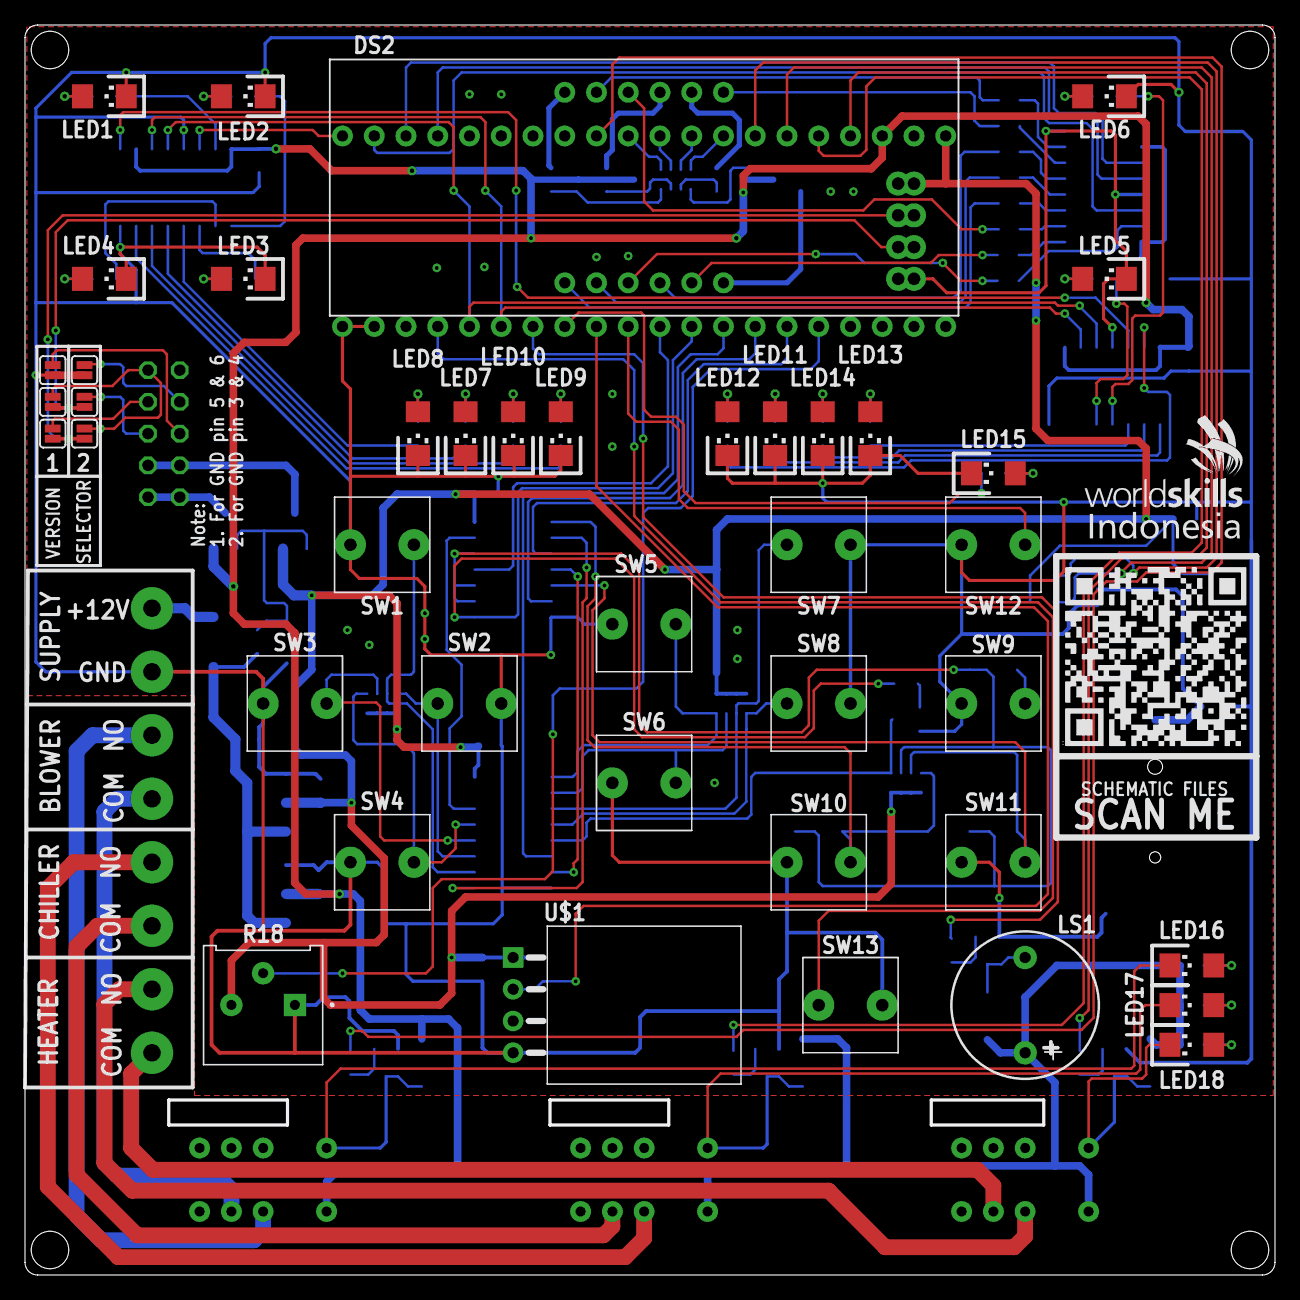
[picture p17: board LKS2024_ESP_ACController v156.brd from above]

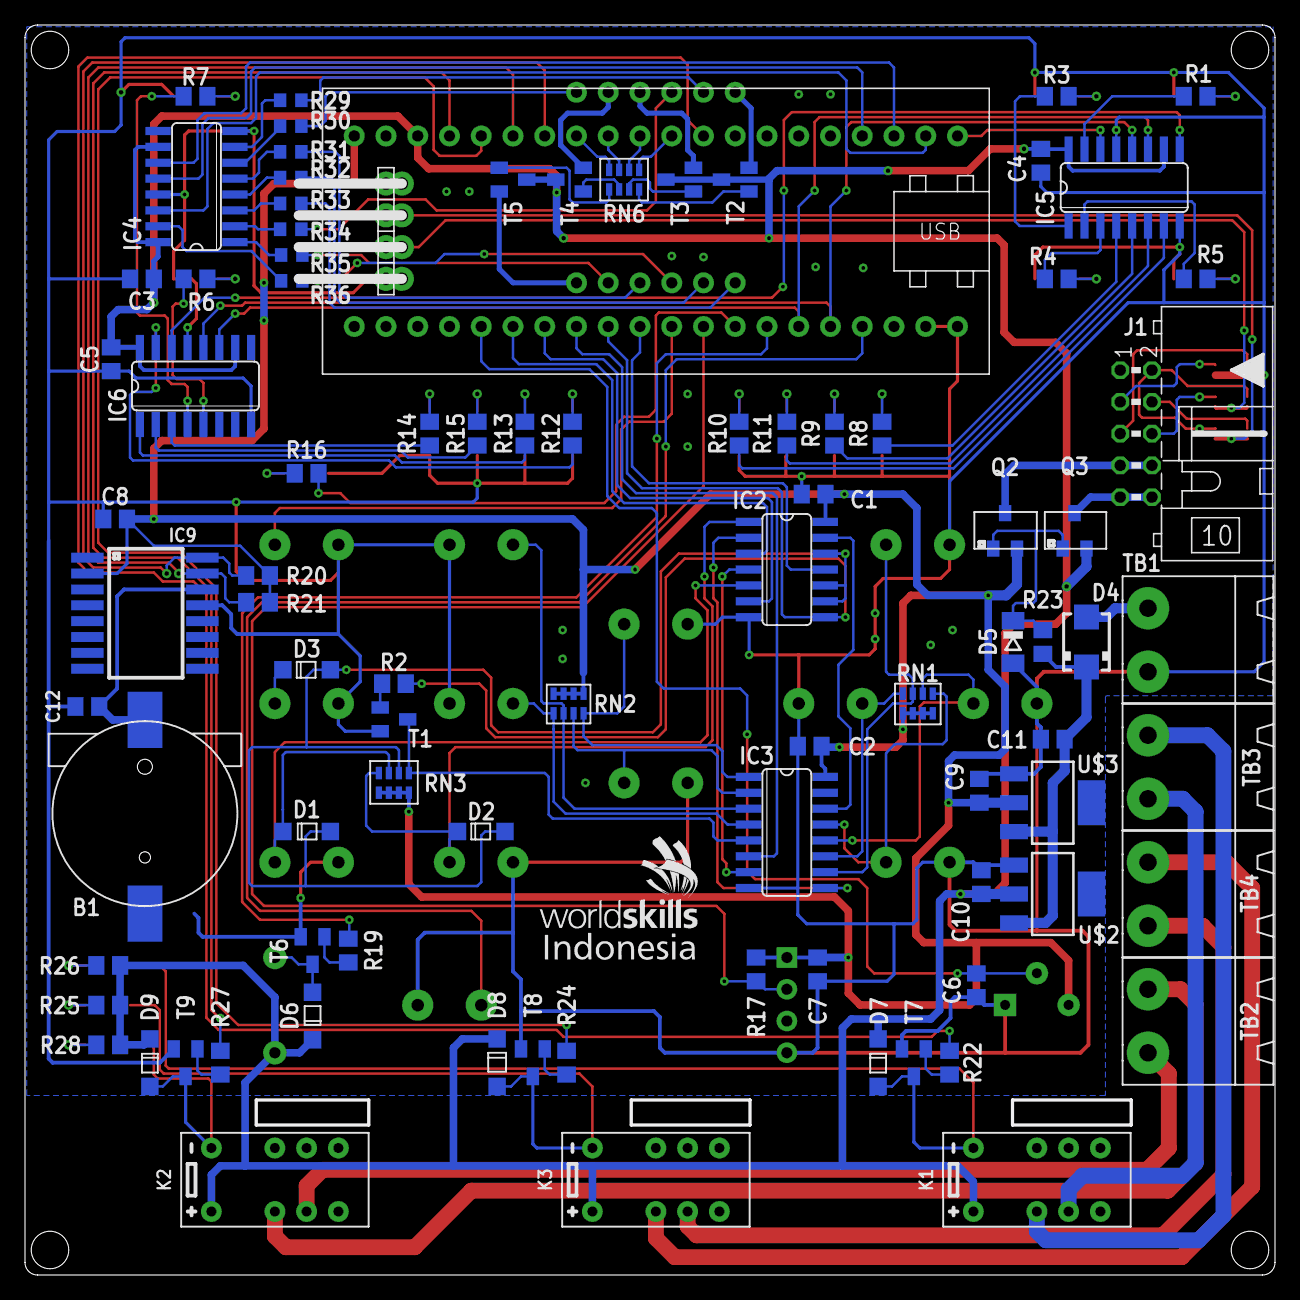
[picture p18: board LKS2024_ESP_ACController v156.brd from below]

Board: 2 copper layers, 100.0 x 100.0 mm, 130 parts (89 on the bottom side), 130 nets.

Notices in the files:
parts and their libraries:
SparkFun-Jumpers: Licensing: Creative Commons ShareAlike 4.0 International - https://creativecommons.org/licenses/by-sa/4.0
